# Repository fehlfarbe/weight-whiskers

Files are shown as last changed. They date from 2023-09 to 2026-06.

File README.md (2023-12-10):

# weight-whiskers

PCB top

This is an ESP32 S2 based smart scale that tracks my cat's weight and sends data via MQTT to my smart home. I did the project to automatically track my sick cat's weight when he visits his toilet. Unfortunately he died in August 2023. So this is dedicated to you, my beloved Schneeball 🖤🌈

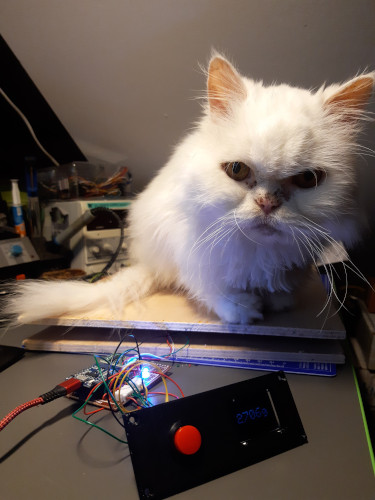
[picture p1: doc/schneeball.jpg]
Schneeball

Schneeball testing the scale

# Hardware

I made a prototype on a solder board with an ESP32 S2 breakout board. I like the WEMOS S2 mini which is very small. You might have to change some pins. Or just use the gerber files and make the PCB. You can find the KiCAD project and gerber files at [hardware](hardware/).

You can connect all load cells that are compatible with the HX711 IC. I'm using [four cells that can measure up to 50Kg](https://de.aliexpress.com/item/1005004867068245.html) because it's easier to keep a big cat toilet balanced.

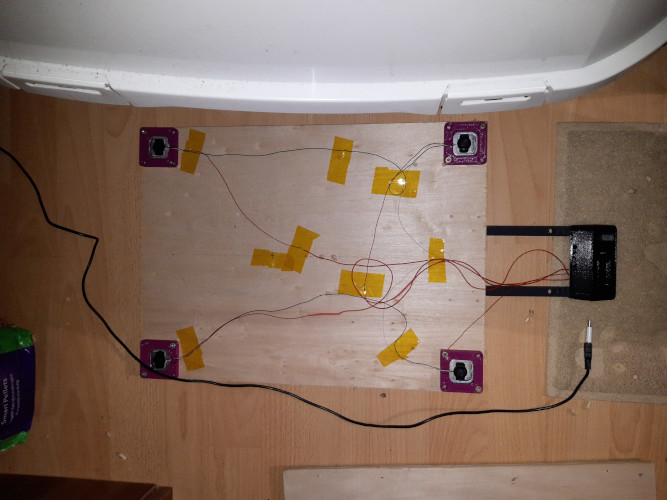
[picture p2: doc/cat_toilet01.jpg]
sensors
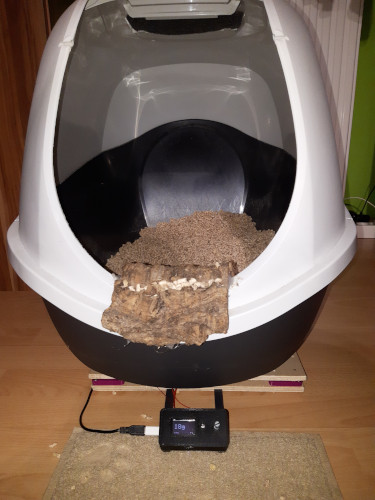
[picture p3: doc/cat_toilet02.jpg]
cat toilet with display
 

## Schematic

schematic
[PDF](doc/pcb_schematic.pdf)

## 2D plot

#### Front

**Important:** Check the VCC and GND position of the display! Some displays have GND on the first pin and VCC on the second like in the rendered image. You need a display with `VCC  | GND | SCL | SDA` pinout as you can see in the 2D front plot.

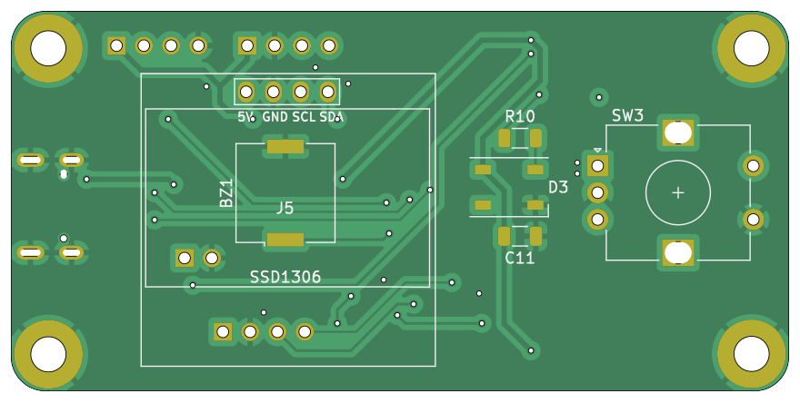
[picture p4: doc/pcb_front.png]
PCB render front PCB front


#### Back
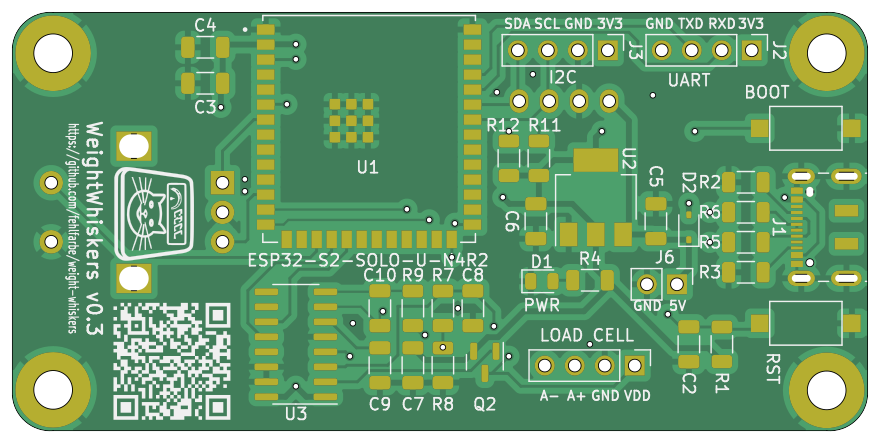
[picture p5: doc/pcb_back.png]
PCB render back PCB back


## 3D rendering

#### Front
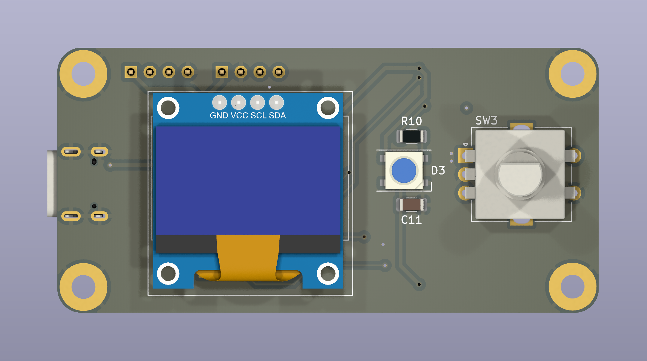
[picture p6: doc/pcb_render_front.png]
PCB render front


#### Back

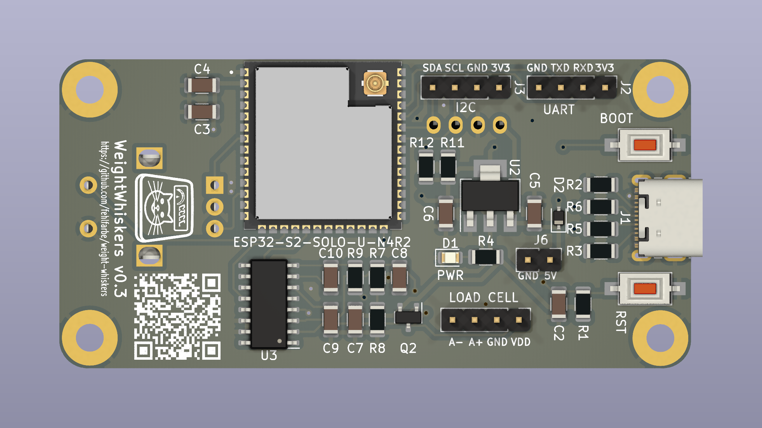
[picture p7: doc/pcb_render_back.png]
PCB render back


## Images
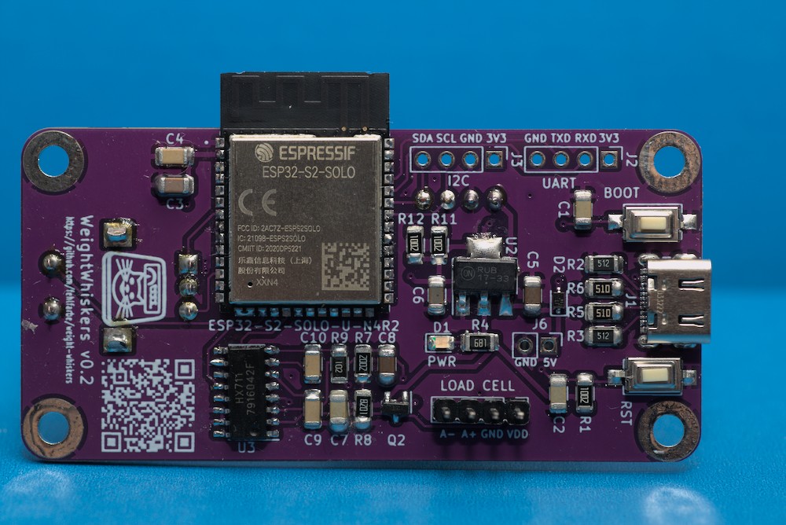
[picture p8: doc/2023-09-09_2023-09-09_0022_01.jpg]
PCB front

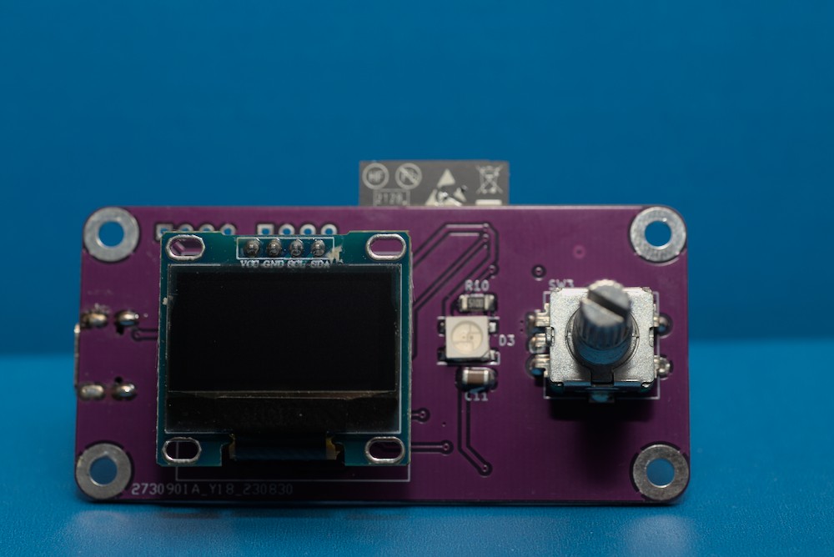
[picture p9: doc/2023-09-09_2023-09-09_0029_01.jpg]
PCB back


# Software

## Installation

Just install [PlatformIO](https://platformio.org/), clone the project, connect the device and run:
`pio run -t upload -e esp32s` to upload the sketch and `pio run -t uploadfs -e esp32s2` to upload the filesystem that contains the config file and web interface. Use the environment `-e esp32s2_ota` if you want to update the device via WiFi.
WARNING: When you update the filesystem you will overwrite the config file and measurements. So please backup it first!

# Usage

On first start the weight-whiskers scale will create an access point that has a config page at <http://192.168.4.1> where you can connect to your local WiFi. If the connection was successful you can find the actual web interface at <http://weight-whiskers.local> in your local network or check your internet router page to get the local IP address.

With a long press on the encoder you can calibrate the load cells with a known weight. The default weight is 500g but you can change it by rotating the encoder (or set it up on the web interface). Just follow the instructions on the display. To tare the scale just short press (<1s) the encoder button.

You can configure the `scale minimum weight` on the web interface. If the cat enters the scale, the LED lights up yellow and the scale measures the weight (with standard deviation) and duration until the cat left the scale. Afterwards the LED lights up green and the result will be stored in the CSV file and sent via MQTT message. If you connected the buzzer, a fancy sound will be played :D

## Web interface

On the web interface you can show, delete and down- and upload the data. The measurements are stored in a CSV file on the device. You can download it and open it in a text editor or import it with a spreadsheet editor. You can also edit the config and show the scale's live data.

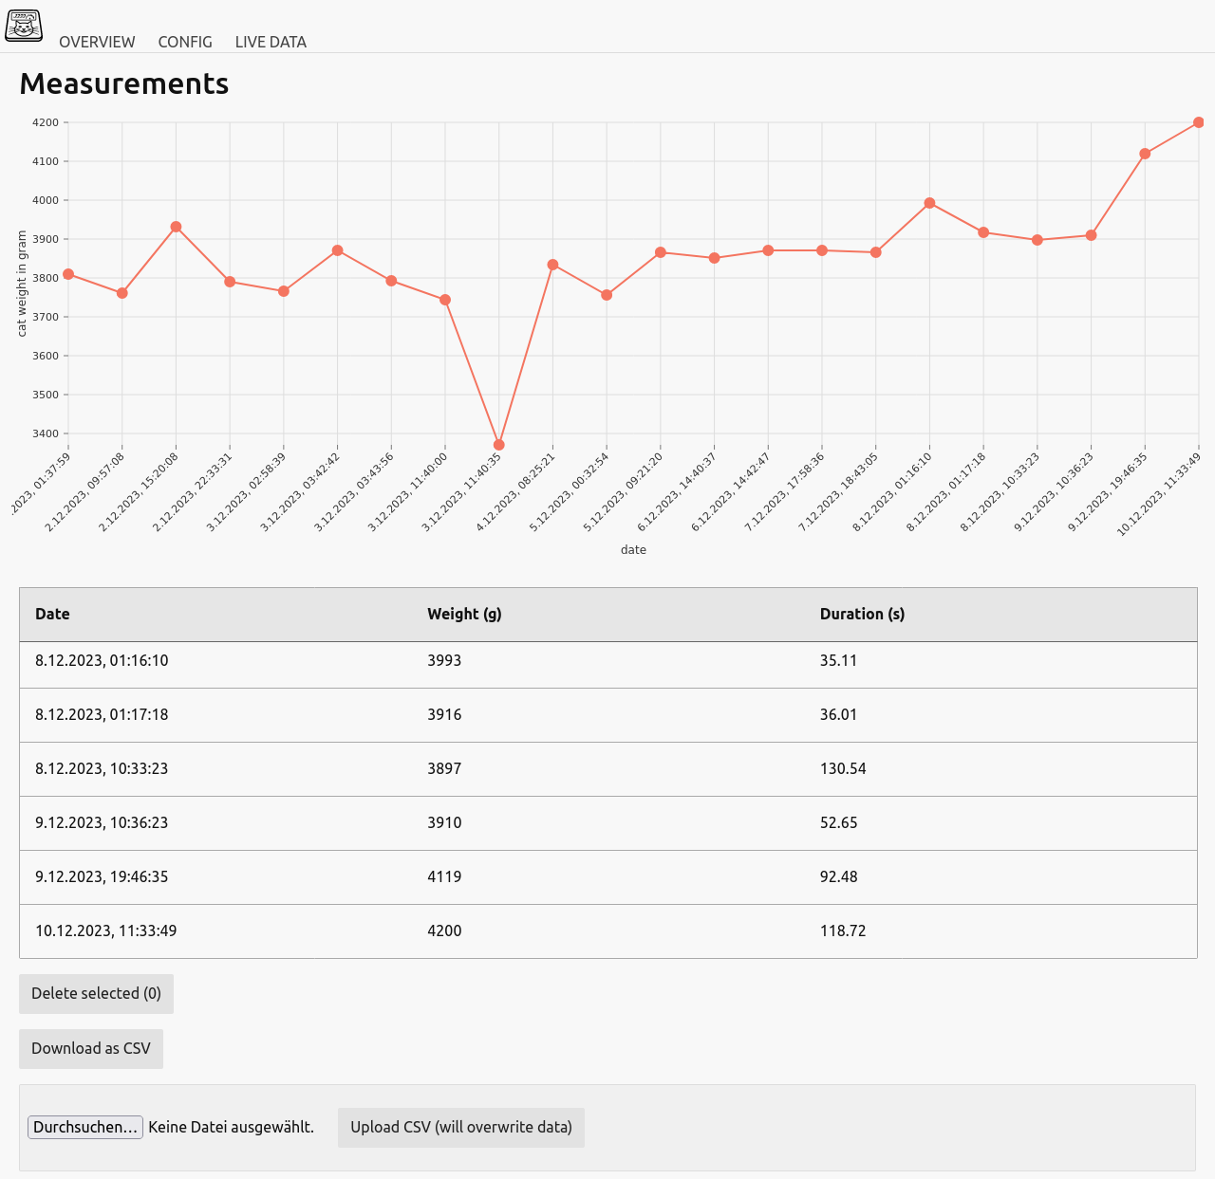
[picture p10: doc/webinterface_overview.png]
Web interface web interface
 
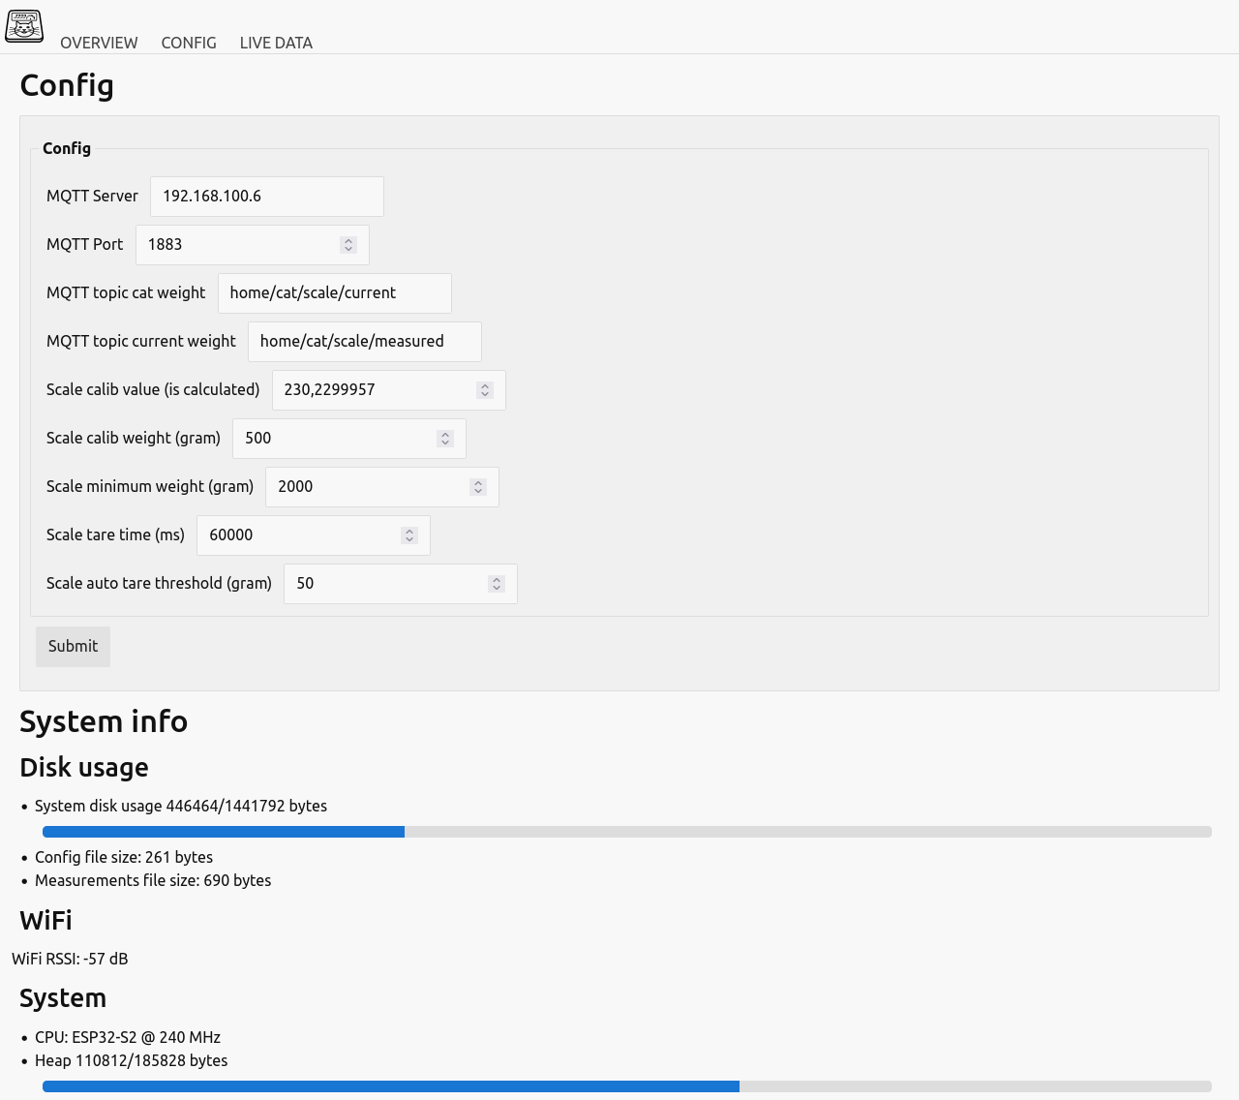
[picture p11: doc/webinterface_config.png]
Web interface web interface
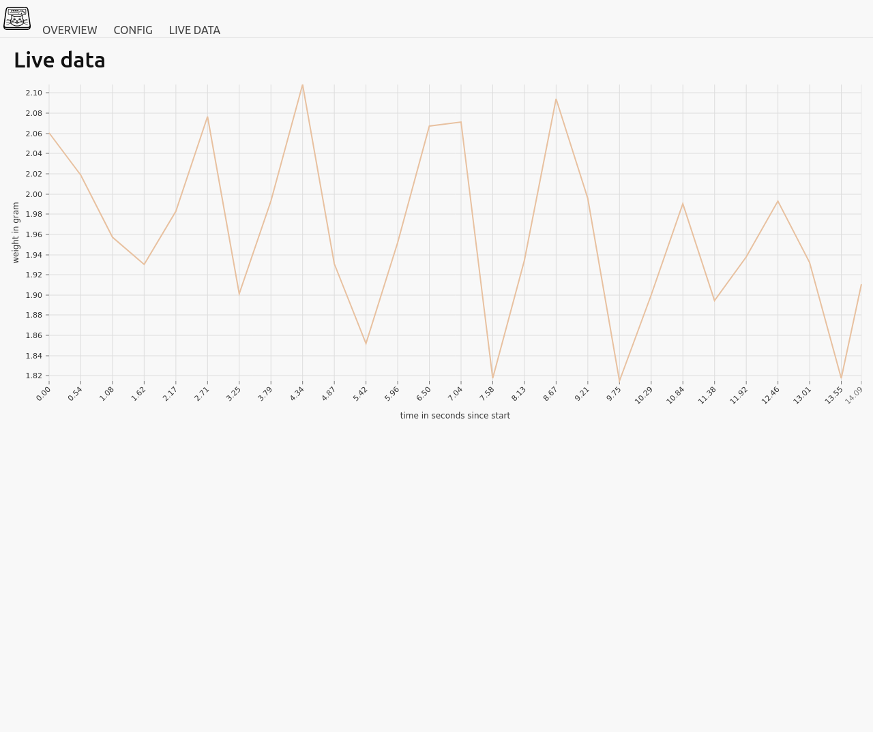
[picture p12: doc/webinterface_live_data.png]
Web interface web interface


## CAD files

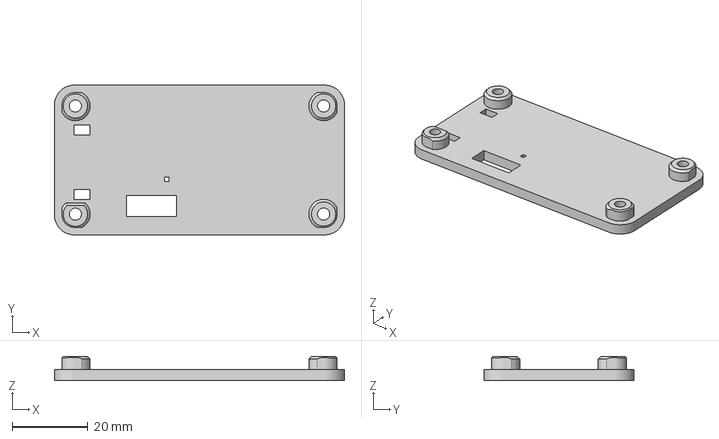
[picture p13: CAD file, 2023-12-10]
hardware/housing/weight-whiskers-back.3mf
76.5 x 39.5 x 6.42 mm

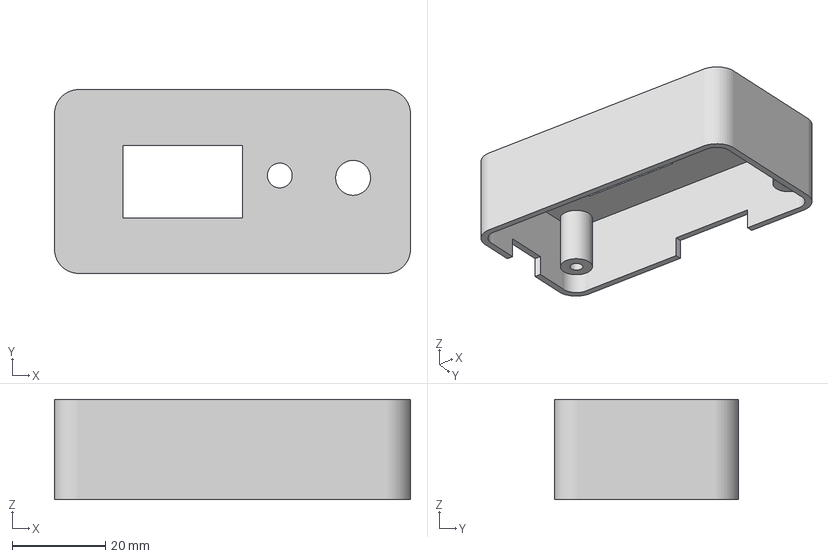
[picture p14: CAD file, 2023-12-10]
hardware/housing/weight-whiskers-housing.3mf
76.5 x 39.5 x 21.5 mm

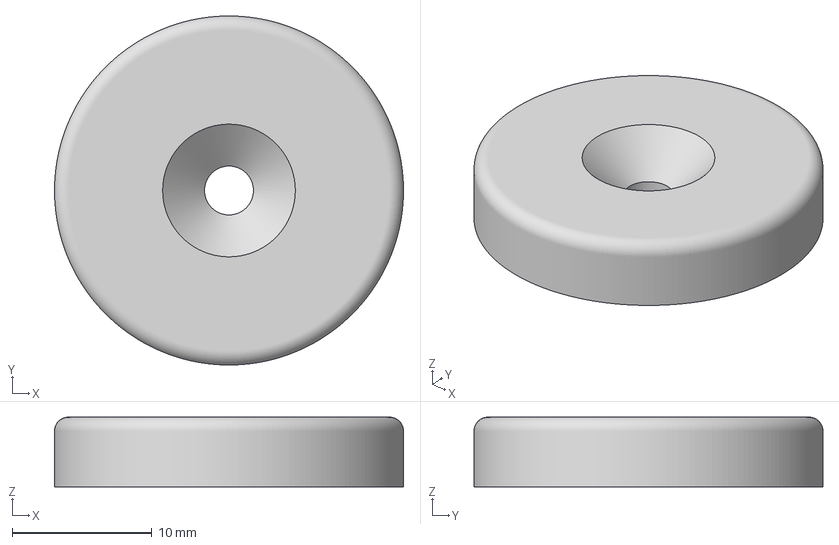
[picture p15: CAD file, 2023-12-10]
hardware/housing/weight-whiskers-foot.3mf
25.0 x 25.0 x 5.00 mm

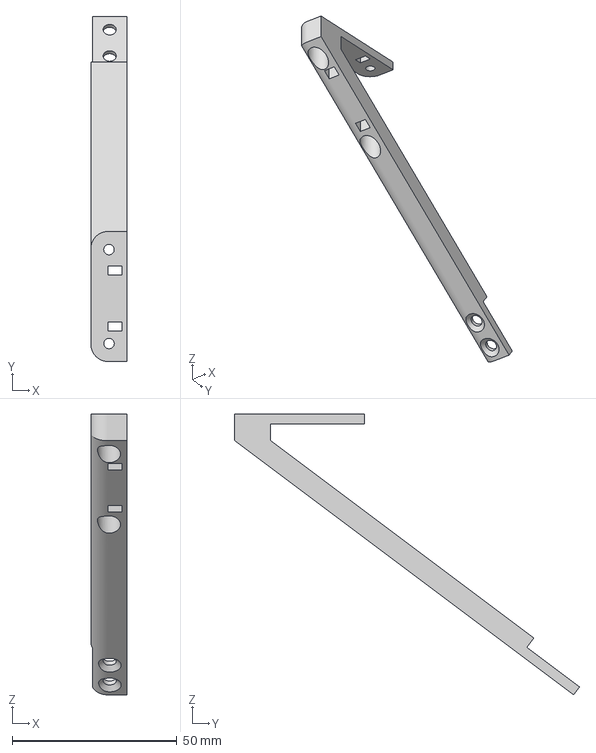
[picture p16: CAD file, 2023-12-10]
hardware/housing/weight-whiskers-stand.3mf
11.0 x 104.8 x 85.2 mm

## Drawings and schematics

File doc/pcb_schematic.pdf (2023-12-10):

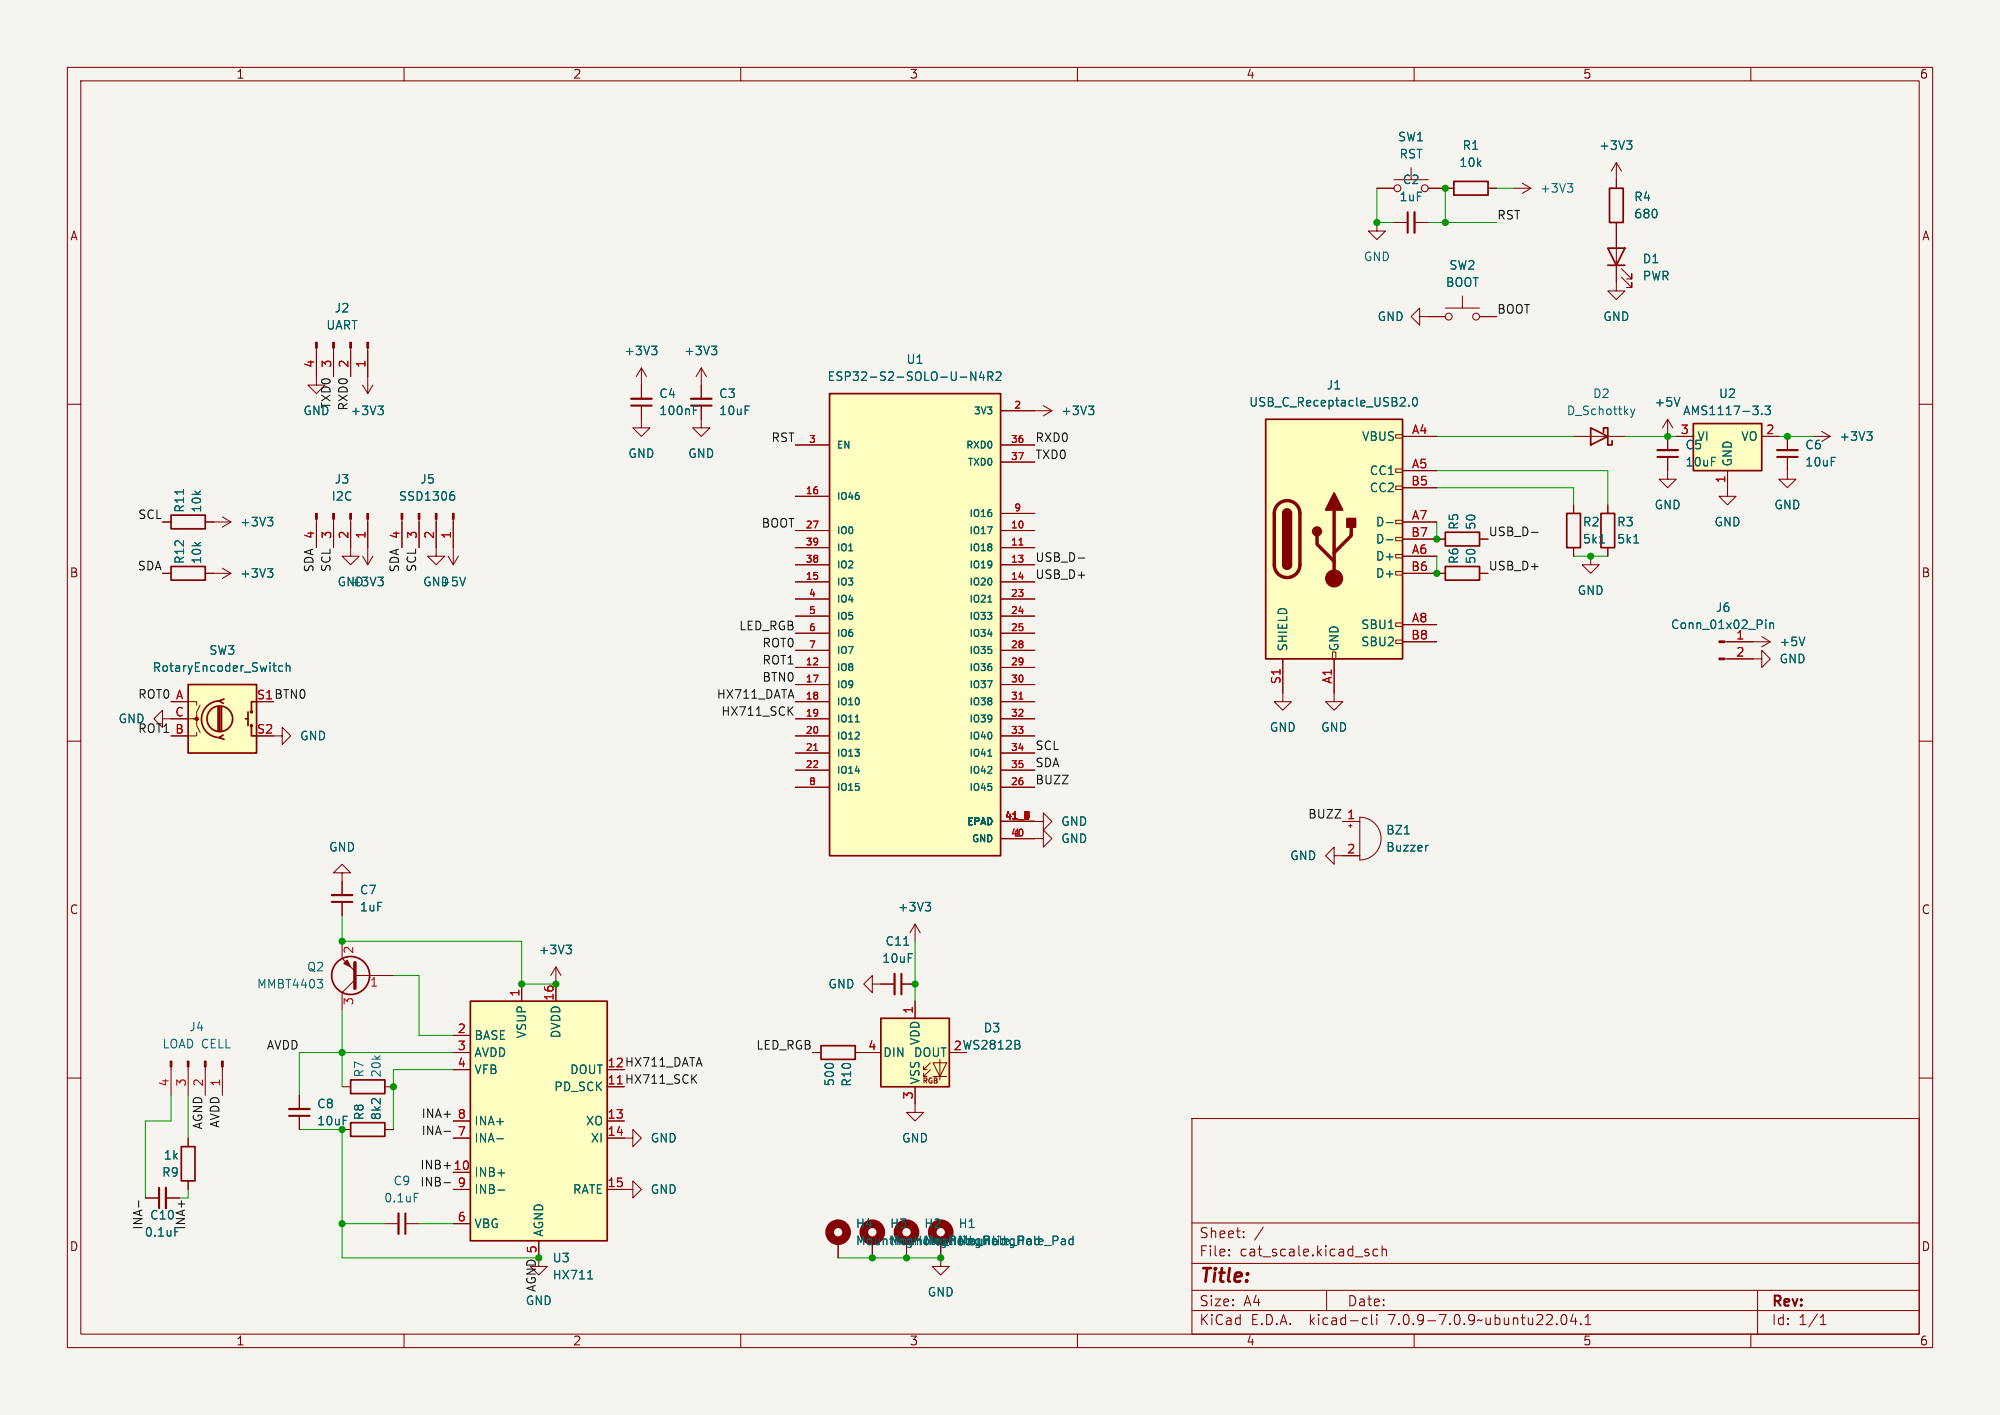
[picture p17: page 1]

Id: 1/1 Title: File: cat_scale.kicad_sch Sheet: /

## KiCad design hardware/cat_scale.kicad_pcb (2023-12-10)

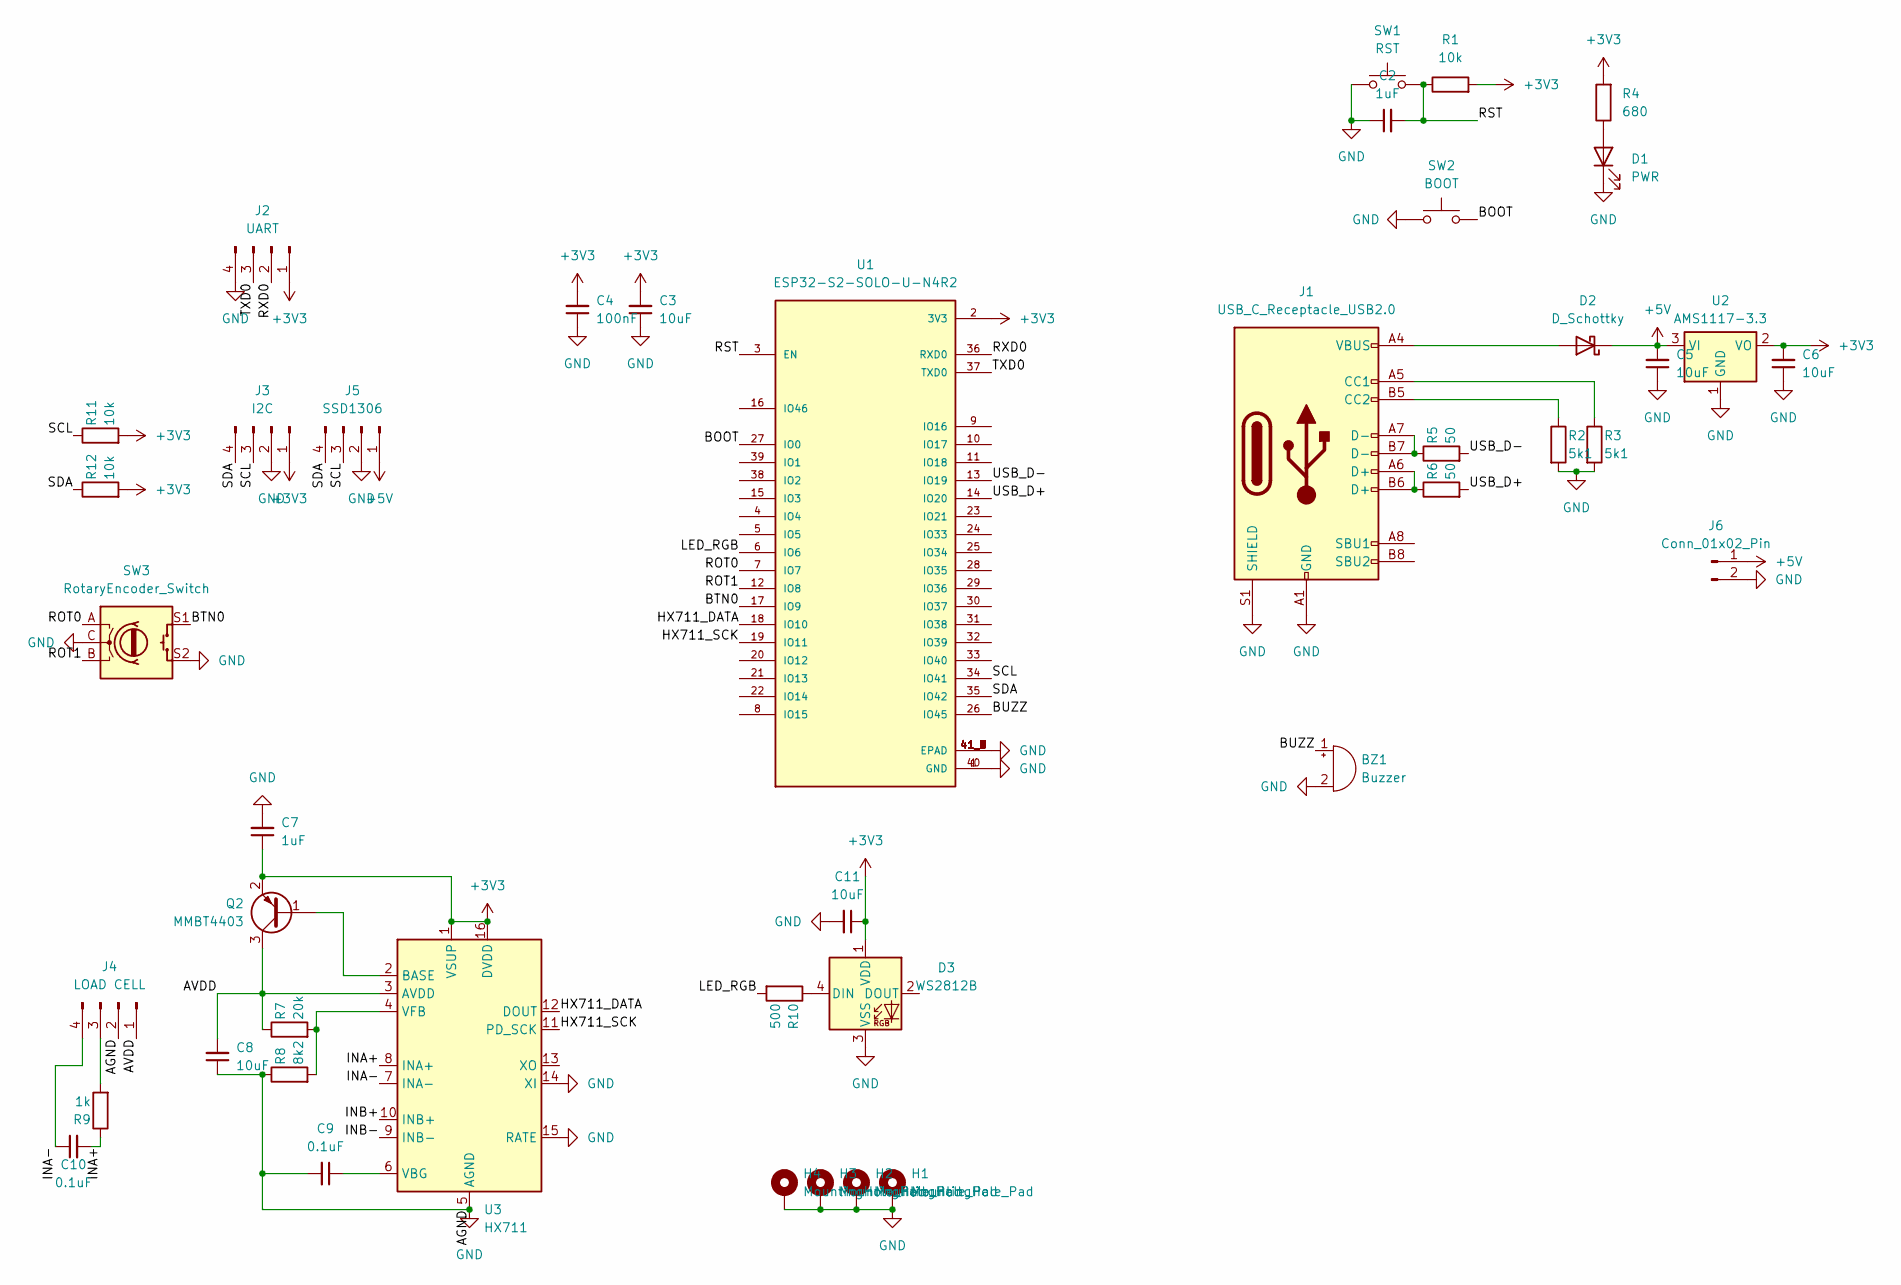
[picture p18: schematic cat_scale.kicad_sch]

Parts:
BZ1: Buzzer; Buzzer_Murata_PKMCS0909E
C2, C7: 1uF; C_1206_3216Metric
C3, C5, C6, C8, C11: 10uF; C_1206_3216Metric
C4: 100nF; C_1206_3216Metric
C9, C10: 0.1uF; C_1206_3216Metric
D1: PWR; LED_0805_2012Metric
D2: D_Schottky; D_SOD-323
D3: WS2812B; LED_WS2812B_PLCC4_5.0x5.0mm_P3.2mm
H1, H2, H3, H4: MountingHole_Pad; MountingHole_3.2mm_M3_Pad
J1: USB_C_Receptacle_USB2.0; USB_C_Receptacle_JAE_DX07S016JA1R1500
J2: UART; PinHeader_1x04_P2.54mm_Vertical
J3: I2C; PinHeader_1x04_P2.54mm_Vertical
J4: LOAD CELL; PinHeader_1x04_P2.54mm_Vertical
J5: SSD1306; 128x64OLED
J6: Conn_01x02_Pin; PinHeader_1x02_P2.54mm_Vertical
Q2: MMBT4403; SOT-23
R1, R11, R12: 10k; R_1206_3216Metric
R2, R3: 5k1; R_1206_3216Metric
R4: 680; R_1206_3216Metric
R5, R6: 50; R_1206_3216Metric
R7: 20k; R_1206_3216Metric
R8: 8k2; R_1206_3216Metric
R9: 1k; R_1206_3216Metric
R10: 500; R_1206_3216Metric
SW1: RST; SW_SPST_CK_RS282G05A3
SW2: BOOT; SW_SPST_CK_RS282G05A3
SW3: RotaryEncoder_Switch; RotaryEncoder_Alps_EC12E-Switch_Vertical_H20mm
U1: ESP32-S2-SOLO-U-N4R2; XCVR_ESP32-S2-SOLO-U-N4R2; PARTREV 1.4
U2: AMS1117-3.3; SOT-223-3_TabPin2
U3: HX711; SOP-16_3.9x9.9mm_P1.27mm

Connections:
+3V3: C3.2, C4.2, C6.2, C7.1, C11.1, D3.1 (VDD), J2.1, J3.1, Q2.2 (E), R1.2, R4.2, R11.2, R12.2, U1.2 (3V3), U2.2 (VO), U3.1 (VSUP), U3.16 (DVDD)
+5V: C5.2, D2.1 (K), J5.1, J6.1, U2.3 (VI)
/AVDD: C8.2, J4.1, Q2.3 (C), R7.1, U3.3 (AVDD)
/BOOT: SW2.2, U1.27 (IO0)
/BTN0: SW3.S1, U1.17 (IO9)
/BUZZ: BZ1.1 (-), U1.26 (IO45)
/HX711_DATA: U1.18 (IO10), U3.12 (DOUT)
/HX711_SCK: U1.19 (IO11), U3.11 (PD_SCK)
/INA+: C10.2, R9.1, U3.8 (INA+)
/INA-: C10.1, J4.4, U3.7 (INA-)
/INB+: U3.10 (INB+)
/INB-: U3.9 (INB-)
/LED_RGB: R10.2, U1.6 (IO6)
/ROT0: SW3.A, U1.7 (IO7)
/ROT1: SW3.B, U1.12 (IO8)
/RST: C2.2, R1.1, SW1.2, U1.3 (EN)
/RXD0: J2.2, U1.36 (RXD0)
/SCL: J3.3, J5.3, R11.1, U1.34 (IO41)
/SDA: J3.4, J5.4, R12.1, U1.35 (IO42)
/TXD0: J2.3, U1.37 (TXD0)
/USB_D+: R6.2, U1.14 (IO20)
/USB_D-: R5.2, U1.13 (IO19)
GND: BZ1.2 (+), C2.1, C3.1, C4.1, C5.1, C6.1, C7.2, C8.1, C9.2, C11.2, D1.1 (K), D3.3 (VSS), H1.1, H2.1, H3.1, H4.1, J1.A1 (GND), J1.A12 (GND), J1.B1 (GND), J1.B12 (GND), J1.S1 (SHIELD), J2.4, J3.2, J4.2, J5.2, J6.2, R2.2, R3.2, R8.1, SW1.1, SW2.1, SW3.C, SW3.S2, U1.1 (GND), U1.40 (GND), U1.41_1 (EPAD), U1.41_2 (EPAD), U1.41_3 (EPAD), U1.41_4 (EPAD), U1.41_5 (EPAD), U1.41_6 (EPAD), U1.41_7 (EPAD), U1.41_8 (EPAD), U1.41_9 (EPAD), U2.1 (GND), U3.5 (AGND), U3.14 (XI), U3.15 (RATE)
unnamed: D1.2 (A), R4.1
unnamed: D2.2 (A), J1.A4 (VBUS), J1.A9 (VBUS), J1.B4 (VBUS), J1.B9 (VBUS)
unnamed: D3.4 (DIN), R10.1
unnamed: J1.A5 (CC1), R3.1
unnamed: J1.B5 (CC2), R2.1
unnamed: J1.A6 (D+), J1.B6 (D+), R6.1
unnamed: J1.A7 (D-), J1.B7 (D-), R5.1
unnamed: J4.3, R9.2
unnamed: Q2.1 (B), U3.2 (BASE)
unnamed: C9.1, U3.6 (VBG)
unnamed: R7.2, R8.2, U3.4 (VFB)

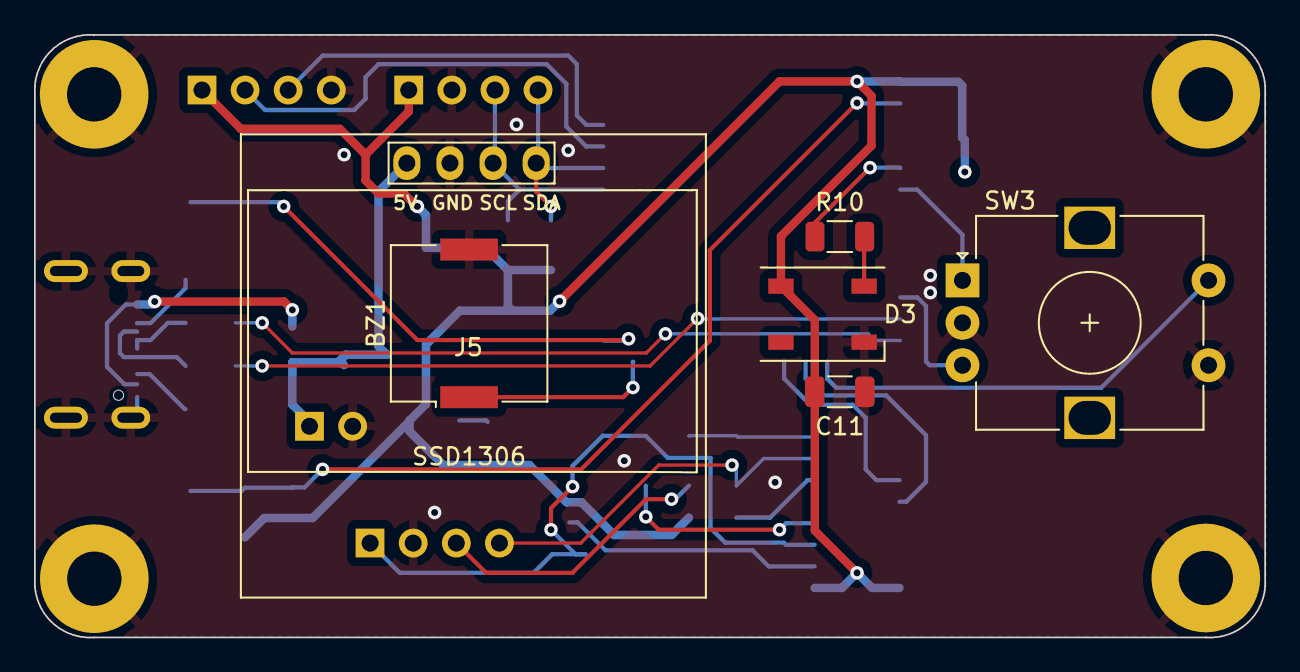
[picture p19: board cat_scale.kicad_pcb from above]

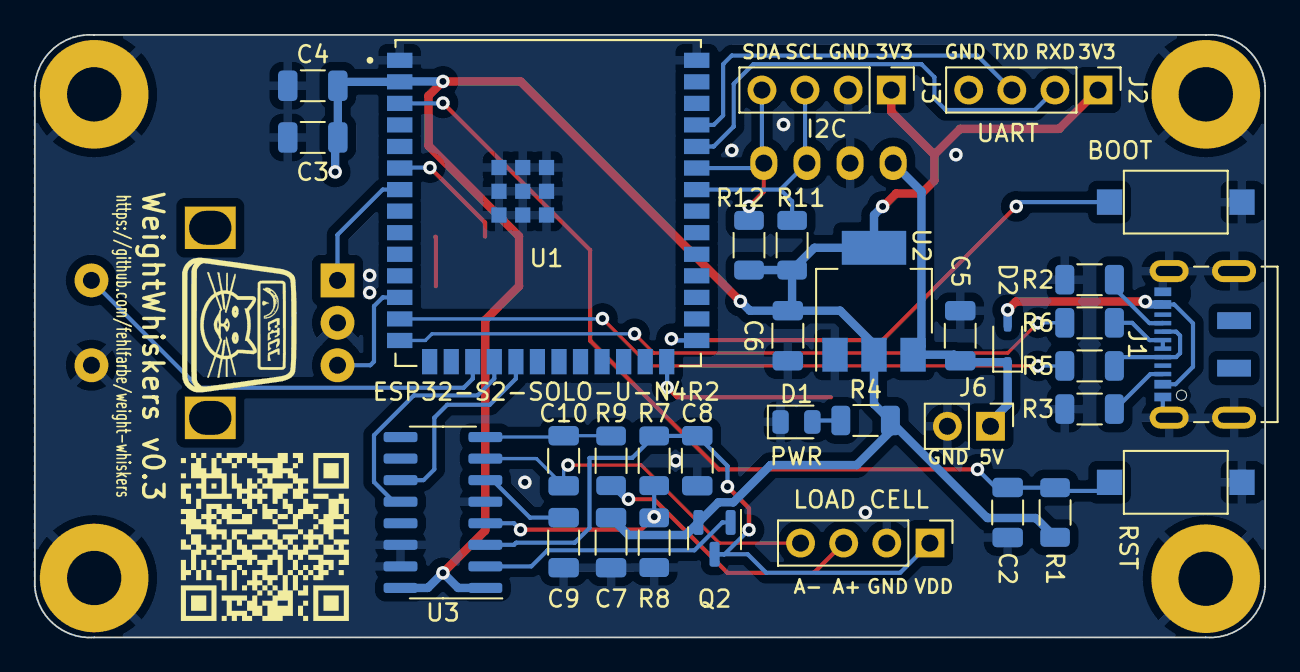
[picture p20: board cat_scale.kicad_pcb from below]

Board: 2 copper layers, 72.5 x 35.5 mm, 43 parts (33 on the bottom side), 32 nets.

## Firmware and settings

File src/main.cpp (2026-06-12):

#include <Arduino.h>
#include <Wire.h>
#include <HX711.h>
#include <LittleFS.h>
#include <Bounce2.h>
#include <AiEsp32RotaryEncoder.h>
#include <WiFi.h>
#include <DNSServer.h>
#include <WebServer.h>
#include <ESPAsyncWebServer.h>
#include <ESPAsyncWiFiManager.h>
#include <ESPmDNS.h>
#include <PubSubClient.h>
#include <FastLED.h>
#include <Filters.h>
#include <ArduinoOTA.h>
#include <AsyncJson.h>
#include <ArduinoJson.h>
#include <melody_player.h>
#include <melody_factory.h>
#include "Display.h"

// Debug
#define SAVE_RAW_VAL 0
// Button
#define ENCODER_BTN 9
#define ENCODER_A 7
#define ENCODER_B 8
// LED
#define LED_EXTRA 6
#define LED_NUM 1
// HX711 circuit wiring
#define LOADCELL_DOUT_PIN 10
#define LOADCELL_SCK_PIN 11
// Display
#define SDA 42
#define SCL 41
// #define SDA 34
// #define SCL 33
#define SSD1306_NO_SPLASH
// Buzzer
#define BUZZER 45
// constants
#define SCALE_DELAY_MS 100
#define SCALE_WS_DELAY_MS 500
#define BUFSIZE 55
#define JSON_BUFFER 2048

#define TAG "WeightWhiskers"

using namespace weightwhiskers;

// display
Display display(&Wire);

// buttons
AiEsp32RotaryEncoder encoder(ENCODER_B, ENCODER_A, ENCODER_BTN, -1, 4, true);

// LED
CRGBArray<LED_NUM> leds;

// buzzer
MelodyPlayer buzzer(BUZZER, 0, LOW);

// scale
HX711 scale;
long scaleLastTimestamp = 0;
long scaleLastWSTimestamp = 0;
long scaleLastTareThreshTimestamp = 0;
FilterOnePole weightLowPass = FilterOnePole(LOWPASS, 0.5, 0);
// DEBUG
time_t startTime = 0;

struct CatMeasurement {
    // UNIX timetamp in seconds
    time_t time = 0;
    // weight in gram
    uint16_t weight = 0.;
    // standard deviation
    float std = 0.;
    // duration in seconds
    float duration = 0.;
    // weight of poo/urine "dropping"
    uint16_t weightDropping = 0;
};
CatMeasurement lastMeasurement;

// fs::LittleFSFS fsWWW;
// fs::LittleFSFS fsConfig;
#define fsWWW LittleFS
#define fsConfig LittleFS
String measurementsFile = "/measurements.csv";
String configFile = "/config.json";

// Config
struct Config {
    // MQTT
    bool mqtt_enabled = false;
    String mqtt_server = "";
    int mqtt_port = 1883;
    String mqtt_user = "kitty";
    String mqtt_pass = "kitty";
    String mqtt_topic_cat_weight = "home/cat/scale/measured";
    String mqtt_topic_current_weight = "home/cat/scale/current";
    // scale
    float scale_calib_value = 1.f;
    int scale_calib_weight = 500; // gram
    int scale_weight_min = 2000; // gram
    // scale tare triggers
    int scale_tare_time = 60000; // millis
    int scale_tare_thresh = 50; // gram
    // presence detection
    float presence_time_min = 5.f;
    // weight deviation filter (0.0 = disabled, 0.2 = ±20%)
    float scale_weight_deviation_percent = 0.f;
};

Config config;

// Weight history for deviation filter (circular buffer for last 5 measurements)
#define WEIGHT_HISTORY_SIZE 5
uint16_t weightHistory[WEIGHT_HISTORY_SIZE] = {0};
int weightHistoryCount = 0; // how many valid measurements we have (0-5)
int weightHistoryIndex = 0; // current write position in circular buffer

// MQTT
TaskHandle_t pTaskMQTT;
QueueHandle_t qMQTT = xQueueCreate(5, sizeof(CatMeasurement));
SemaphoreHandle_t semMQTT;

// WiFi
WiFiClient espClient;
PubSubClient mqtt(espClient);
DNSServer dns;
AsyncWebServer server(80);
AsyncWiFiManager wifiManager(&server, &dns);
AsyncWebSocket ws("/ws");

// declarations
bool loadConfig();
bool saveConfig();
void printConfig();
void applyConfig();
void listDir(fs::FS& fs, const char* dirname, uint8_t levels);
void setupScale();
void tare(int count);
void calibrate(long weight);
void apCallback(AsyncWiFiManager* mgr);
void WiFiEvent(WiFiEvent_t event);
void handleConfig(AsyncWebServerRequest* request);
void handleConfigUpdate(
    AsyncWebServerRequest* request, uint8_t* data, size_t len, size_t index, size_t total);
void handeMeasurementsUpload(AsyncWebServerRequest* request, String filename, size_t index,
    uint8_t* data, size_t len, bool final);
void handleMeasurements(AsyncWebServerRequest* request);
void handleSystem(AsyncWebServerRequest* request);
void onEvent(AsyncWebSocket* server, AsyncWebSocketClient* client, AwsEventType type, void* arg,
    uint8_t* data, size_t len);
void setupMQTT();
void sendMQTTCatWeights(const CatMeasurement& measurement);
void createMeasurementsFile();
void initWeightHistory();
void addToWeightHistory(uint16_t weight);
float calculateAverageWeight();
bool isMeasurementValid(uint16_t weight, float deviationPercent);
bool writeMeasurement(CatMeasurement& m);
void playToneStart();
void playToneSuccess();
void taskMQTT(void* parameter);

void IRAM_ATTR readEncoderISR() { encoder.readEncoder_ISR(); }

void setup()
{
    esp_log_level_set(TAG, ESP_LOG_VERBOSE);

    // Serial
    Serial.begin(115200);
    Serial.setDebugOutput(true);
    ESP_LOGI(TAG, "Weight whiskers");

    // setup pins
    pinMode(BUZZER, OUTPUT);
    digitalWrite(BUZZER, LOW);

    // setup encoder
    encoder.begin();
    encoder.setup(readEncoderISR);
    encoder.disableAcceleration();

    // display
    Wire.begin(SDA, SCL);
    display.begin();
    display.drawBootScreen();

    // LED
    FastLED.addLeds<NEOPIXEL, LED_EXTRA>(leds, LED_NUM);
    FastLED.setBrightness(50);
    leds[0] = CRGB::Yellow;
    FastLED.show();

    // start sound
    playToneStart();

    // config filesystem and config
    if (!fsConfig.begin(true, "/littlefs", 10, "spiffs")) {
        ESP_LOGE(TAG, "An Error has occurred while mounting config");
        display.drawError("FS Error");
        while (true) {
            leds[0] = CRGB::Red;
            FastLED.show();
            delay(500);
            leds[0] = CRGB::Black;
            FastLED.show();
            delay(500);
        }
    }

    // load config or create config file with default values if not existing
    listDir(fsConfig, "/", 4);
    if (!loadConfig()) {
        ESP_LOGI(TAG, "Cannot load config, saving default config file");
        saveConfig();
    }
    printConfig();

    // create measurements file if not existing
    createMeasurementsFile();
    
    // initialize weight history from existing measurements
    initWeightHistory();

    listDir(fsConfig, "/", 4);

    // Setup WiFi
    ESP_LOGI(TAG, "WiFi autoconnect...");
    display.drawWiFi();
    WiFi.setAutoReconnect(true);
    WiFi.onEvent(WiFiEvent);
    wifiManager.setAPCallback(apCallback);
    if (!wifiManager.autoConnect("weight-whiskers")) {
        Serial.println("failed to connect, we should reset as see if it connects");
    }

    // setup mDNS
    MDNS.begin("weight-whiskers");
    ESP_LOGI(TAG, "Visit the config site at http://weight-whiskers.local");

    // Set up required URL handlers on the web server.
    // static files, cached for 1 month
    // if (!fsWWW.begin(true, "/www", 10, "www")) {
    //     Serial.println("An Error has occurred while mounting www");
    //     display.drawError("FS Error");
    //     while (true) {
    //         leds[0] = CRGB::Yellow;
    //         FastLED.show();
    //         delay(500);
    //         leds[0] = CRGB::Black;
    //         FastLED.show();
    //         delay(500);
    //     }
    // }
    listDir(fsWWW, "/", 4);
    server.serveStatic("/", fsWWW, "/www/")
        .setDefaultFile("index.html")
        .setCacheControl("max-age=2678400");
    server.serveStatic("/config", fsWWW, "/www/index.html")
        .setDefaultFile("index.html")
        .setCacheControl("max-age=2678400");
    server.serveStatic("/live", fsWWW, "/www/index.html")
        .setDefaultFile("index.html")
        .setCacheControl("max-age=2678400");
    server.on("/api/config", HTTP_POST, handleConfig, nullptr, handleConfigUpdate);
    server.on("/api/measurements", HTTP_POST, handleMeasurements, handeMeasurementsUpload);
    server.on("/api/raw", HTTP_GET, [](AsyncWebServerRequest* request) {
        request->send(fsConfig, "/rawvalues.csv", "text/csv");
    });
    server.on("/api/system", HTTP_GET, handleSystem);
    server.on("/api/reboot", HTTP_GET, [](AsyncWebServerRequest* request) { ESP.restart(); });
    // attach AsyncWebSocket
    ws.onEvent(onEvent);
    server.addHandler(&ws);
    server.begin();

    // setup time
    display.drawText("NTP...");
    configTime(0, 0, "pool.ntp.org");
    time(&startTime);

    // setup MQTT
    semMQTT = xSemaphoreCreateBinary();
    xSemaphoreGive(semMQTT);
    setupMQTT();
    xTaskCreate(taskMQTT, "taskMQTT", getArduinoLoopTaskStackSize(), NULL, 1, &pTaskMQTT);

    // setup scale
    setupScale();

    // setup OTA
    ArduinoOTA.setHostname("weight-whiskers");
    ArduinoOTA.setPassword("weight-whiskers");

    ArduinoOTA.onStart([]() {
        ESP_LOGI(TAG, "Start");
        display.drawOTA(0);
    });
    ArduinoOTA.onEnd([]() {
        ESP_LOGI(TAG, "OTA Finished!");
        display.drawOTA(1.);
    });
    ArduinoOTA.onProgress([](unsigned int progress, unsigned int total) {
        float percentage = (1. / total) * progress;
        ESP_LOGI(TAG, "Update:%u%%\r", percentage * 100);
        display.drawOTA(percentage);
    });
    ArduinoOTA.onError([](ota_error_t error) {
        ESP_LOGE(TAG, "Error[%u]: ", error);
        display.drawOTA(0);
        if (error == OTA_AUTH_ERROR)
            ESP_LOGE(TAG, "Auth Failed");
        else if (error == OTA_BEGIN_ERROR)
            ESP_LOGE(TAG, "Begin Failed");
        else if (error == OTA_CONNECT_ERROR)
            ESP_LOGE(TAG, "Connect Failed");
        else if (error == OTA_RECEIVE_ERROR)
            ESP_LOGE(TAG, "Receive Failed");
        else if (error == OTA_END_ERROR)
            ESP_LOGE(TAG, "End Failed");
    });
    ArduinoOTA.begin();

    // success!
    leds[0] = CRGB::Green;
    FastLED.show();
    ESP_LOGI(TAG, "Setup finished!");
}

void loop()
{
    // clear ws clients
    ws.cleanupClients();

    // over the air update
    ArduinoOTA.handle();

    // button handling
    if (encoder.isEncoderButtonClicked()) {
        tare(10);
    } else {
        auto beforeDown = millis();
        while (encoder.isEncoderButtonDown()) {
            auto now = millis();
            if ((now - beforeDown) > 1000) {
                calibrate(config.scale_calib_weight);
            }
        }
    }

    // measure weight
    auto current = millis();
    if (scale.wait_ready_timeout(1000)) {
        auto weight = scale.get_units(2);
        auto raw = scale.get_value();
        weightLowPass.input(weight);
        // weightLowPass.print();
        ESP_LOGV(TAG, "Current measurement=%fg raw=%f lowPass=%f Y=%f up since=%d\n", weight, raw,
            weightLowPass.output(), weightLowPass.Y, startTime);
        if (current - scaleLastWSTimestamp > SCALE_WS_DELAY_MS) {
            ws.printfAll("{\"timestamp\": %lu, \"weight\": %f, \"weight_unfiltered\": %f}", current,
                weightLowPass.output(), weight);
            scaleLastWSTimestamp = current;
        }
    } else {
        ESP_LOGE(TAG, "HX711 not found.");
        return;
    }

    if (current - scaleLastTimestamp > SCALE_DELAY_MS) {
        if (weightLowPass.output() > config.scale_weight_min) {
// debug: write values to file
#ifdef SAVE_RAW_VAL
            File rawValues = fsConfig.open("/rawvalues.csv", FILE_WRITE);
            rawValues.println("time,raw,mean,std");
#endif
            // cat sits on the throne
            leds[0] = CRGB::Yellow;
            FastLED.show();
            // prepare duration and temp value
            auto presenceStart = current;
            long duration = 0;
            float bestWeightStd = infinityf();
            float bestWeight = 0;
            // prepare filter
            auto statistics = RunningStatistics();
            statistics.setWindowSecs(config.presence_time_min);
            statistics.setInitialValue(weightLowPass.output());
            // run measurement
            while (weightLowPass.output() > config.scale_weight_min) {
                auto value = scale.get_units(2);
                duration = (millis() - presenceStart) / 1000.;
                weightLowPass.input(value);
                statistics.input(value);
#ifdef SAVE_RAW_VAL
                rawValues.printf("%lu,%.2f,%.2f,%.2f\n", millis() - presenceStart, value,
                    statistics.mean(), statistics.sigma());
#endif
                display.drawWeightScreen(weightLowPass.output(), lastMeasurement.weight, (100./config.presence_time_min)*duration);
                // use value with lowes std dev when minimum presence time is reached
                if (duration > config.presence_time_min && statistics.sigma() < bestWeightStd) {
                    bestWeightStd = statistics.sigma();
                    bestWeight = statistics.mean();
                }
                delay(10);
            }
#ifdef SAVE_RAW_VAL
            rawValues.close();
#endif
            // cat left the throne, save measurement if minimum presence time was reached
            if (duration > config.presence_time_min) {
                ESP_LOGI(TAG, "Got new meowsurement!");
                // show success
                leds[0] = CRGB::Green;
                FastLED.show();
                display.drawWeightScreen(bestWeight, lastMeasurement.weight);
                playToneSuccess();
                // wait for settlement to measure droppings and write measurement
                delay(5000);
                CatMeasurement measurement;
                time(&measurement.time); // Get current timestamp
                measurement.weight = bestWeight;
                measurement.std = bestWeightStd;
                measurement.duration = duration;
                measurement.weightDropping = max(0, (int)scale.get_units(10));
                // write data to file
                writeMeasurement(measurement);
                // send data to MQTT
                if (config.mqtt_enabled) {
                    ESP_LOGI(TAG, "MQTT enabled, sending message to queue");
                    xQueueSend(qMQTT, &lastMeasurement, 0);
                } else {
                    ESP_LOGI(TAG, "MQTT not enabled");
                }
                // save last measurement
                lastMeasurement = measurement;
            }
            delay(1000);
            tare(10);
        }

        // write weight to display
        display.drawWeightScreen(weightLowPass.output(), lastMeasurement.weight);

        // tare if necessary
        if (abs(weightLowPass.output()) < config.scale_tare_thresh) {
            scaleLastTareThreshTimestamp = 0;
        } else {
            if (!scaleLastTareThreshTimestamp || current < scaleLastTareThreshTimestamp) {
                scaleLastTareThreshTimestamp = current;
            } else if (current - scaleLastTareThreshTimestamp > config.scale_tare_time) {
                tare(10);
            }
        }
    }

    // reset LED
    leds[0] = CRGB::Black;
    FastLED.show();
}

void setupScale()
{
    display.drawText("Setup scale");
    scale.begin(LOADCELL_DOUT_PIN, LOADCELL_SCK_PIN);
    scale.set_scale(config.scale_calib_value); // set calibrated scale value from config
    tare(10);
}

void tare(int count = 10)
{
    display.drawTare();
    scale.tare(count);
}

void calibrate(long weight)
{
    ESP_LOGI(TAG, "Calibrate...");

    // setup scale
    scale.set_scale();
    scale.tare();

    // place weight
    display.drawCalib(weight);
    Serial.printf("Place %ld and press\n", weight);
    // wait for button release
    while (encoder.isEncoderButtonDown()) {
        delay(10);
    }
    // wait for button press
    encoder.reset();
    long difference = 0;
    while (!encoder.isEncoderButtonDown()) {
        difference = encoder.readEncoder();
        Serial.printf("Difference %ld %d\n", difference, encoder.encoderChanged());
        display.drawCalib(weight + difference);
        Serial.printf("Place %ld and press\n", weight + difference);
    }
    Serial.println("clicked");
    encoder.reset();
    while (encoder.isEncoderButtonDown()) {
        delay(10);
    }
    weight += difference;

    // show state
    display.drawText("Calibrating...");

    // measure and calculate scale
    float value = scale.get_units(10) / weight;
    scale.set_scale(value);

    // write to file
    Serial.printf("Write scale %f to file\n", value);
    config.scale_calib_value = value;
    saveConfig();

    // show ok!
    display.drawText("Calibrated!");
    Serial.printf("Calibrated!\n");
    delay(1000);
}

void listDir(fs::FS& fs, const char* dirname, uint8_t levels)
{
    Serial.printf("Listing directory: %s\n", dirname);

    File root = fs.open(dirname, FILE_READ, false);
    if (!root) {
        Serial.println("Failed to open directory");
        return;
    }
    if (!root.isDirectory()) {
        Serial.println("Not a directory");
        return;
    }

    File file = root.openNextFile();
    while (file) {
        if (file.isDirectory()) {
            Serial.print("  DIR : ");
            Serial.println(file.name());
            if (levels) {
                listDir(
                    fs, (String(dirname) + String("/") + String(file.name())).c_str(), levels - 1);
            }
        } else {
            Serial.print("  FILE: ");
            Serial.print(file.name());
            Serial.print("  SIZE: ");
            Serial.println(file.size());
        }
        file = root.openNextFile();
    }
}

void apCallback(AsyncWiFiManager* mgr)
{
    Serial.println("Started AP");
    display.drawWiFiAPMode();
    leds[0] = CRGB::Blue;
    FastLED.show();
}

/**
 * @brief handles WiFi events and auto reconnects
 *
 */
void WiFiEvent(WiFiEvent_t event)
{
    switch (event) {
    case ARDUINO_EVENT_WIFI_AP_START:
        ESP_LOGI(TAG, "AP Started");
        leds[0] = CRGB::Blue;
        FastLED.show();
        break;
    case ARDUINO_EVENT_WIFI_AP_STACONNECTED:
        ESP_LOGI(TAG, "AP user connected");
        leds[0] = CRGB::Aqua;
        FastLED.show();
        break;
    case ARDUINO_EVENT_WIFI_AP_STOP:
        ESP_LOGI(TAG, "AP Stopped");
        break;
    case ARDUINO_EVENT_WIFI_STA_START:
        ESP_LOGI(TAG, "STA Started");
        break;
    case ARDUINO_EVENT_WIFI_STA_CONNECTED:
        ESP_LOGI(TAG, "STA Connected");
        break;
    case ARDUINO_EVENT_WIFI_STA_GOT_IP6:
        ESP_LOGI(TAG, "STA IPv6: ");
        // ESP_LOGI( TAG, "%s", WiFi.localIPv6().toString());
        break;
    case ARDUINO_EVENT_WIFI_STA_GOT_IP:
        // ESP_LOGI( TAG, "STA IPv4: ");
        ESP_LOGI(TAG, "%s", WiFi.localIP().toString().c_str());
        break;
    case ARDUINO_EVENT_WIFI_STA_DISCONNECTED:
    case ARDUINO_EVENT_WIFI_STA_LOST_IP:
        ESP_LOGI(TAG, "STA Disconnected -> reconnect");
        WiFi.reconnect();
        break;
    case ARDUINO_EVENT_WIFI_STA_STOP:
        ESP_LOGI(TAG, "STA Stopped");
        break;
    default:
        break;
    }
    ESP_LOGI(TAG, "WiFi mode %d", WiFi.getMode());
}

void handleConfig(AsyncWebServerRequest* request)
{
    // printConfig();
    ESP_LOGI(TAG, "serving config");
    request->send(fsConfig, configFile, "application/json");
}

void handleConfigUpdate(
    AsyncWebServerRequest* request, uint8_t* data, size_t len, size_t index, size_t total)
{
    ESP_LOGI(TAG, "Update config. Config size: %d/%d bytes", len, total);
    if (len == total) {
        DynamicJsonDocument doc(JSON_BUFFER);
        DeserializationError error = deserializeJson(doc, data);

        // Test if parsing succeeds.
        if (error) {
            ESP_LOGE(TAG, "deserializeJson() failed: %s", error.c_str());
            request->send(500, "text/html", error.c_str());
            return;
        }

        // open file
        File file = fsConfig.open(configFile, FILE_WRITE);

        // Serialize JSON to file
        if (serializeJson(doc, file) == 0) {
            ESP_LOGE(TAG, "Failed to write to file");
            request->send(500, "text/html", "Failed to write to file");
            return;
        }

        // Close the file
        file.close();

        // load config and apply new settings

        loadConfig();
        applyConfig();
    }
}

void handeMeasurementsUpload(AsyncWebServerRequest* request, String filename, size_t index,
    uint8_t* data, size_t len, bool final)
{
    ESP_LOGI(TAG, "Replace measurements file. CSV size: %d bytes\n", len);
    // open new file if index is zero, else append data
    File file = fsConfig.open(measurementsFile, index == 0 ? FILE_WRITE : FILE_APPEND);

    // write data
    file.write(data, len);

    // Close the file
    file.close();
}
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

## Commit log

2023-07-14 Added PCB layout
    [cat_scale.kicad_pcb, cat_scale.kicad_sch]
2023-08-02 Fixed PCB design
    [cat_scale.csv, cat_scale.kicad_pcb, cat_scale.kicad_sch]
2023-08-10 * Cleanup dependencies * Enabled ArduinoOTA * Added WebSocket sender for live data * Improved button handling for tare/calibration
2023-08-26 * Refactoring: moved display stuff to class * measurements contain duration instead of variance * added minimum presence time to config * added support for buzzer that plays a sound after cat finishe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
    [main.cpp]
2023-08-26 * PCB: Added buzzer
    [cat_scale.kicad_pcb, cat_scale.kicad_sch]
2023-09-15 * Added encoder support to change calibration weight * Added buzzer that plays a melody on start/measurement
    [main.cpp]
2023-09-15 Updated PCB and added images of the PCB to README
    [cat_scale.kicad_pcb]
2023-09-15 Added new arguments to encoder constructor
2023-12-05 Connect live measurements WebSocket to current host
2023-12-10 Updated PCB and README
    [cat_scale-B_Cu.gbr, cat_scale-B_Mask.gbr, cat_scale-B_Paste.gbr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]
2024-01-16 * Fixed bug in WiFi reconnect * Saving measurement with lowest std deviation * Plotting std deviation hose in web interface * Saving measurement with lowest std deviation
    [main.cpp]
2024-02-14 Added simple time filter for web interface Measurements page
2024-02-14 Additional time filter for web interface Measurements page
2024-02-14 Fixed negative / too big values for droppings in csv data
    [main.cpp]
2024-02-15 Fixed date format bug in filtering measurements
2024-10-10 * Updated ESPAsyncWebServer * added some debug output for WebSocket * added custom partitions.csv
    [partitions.csv]
2025-01-11 Added reboot API command
    [main.cpp]
2025-10-27 Fix crashes because off filled MQTT measurements buffer
    [main.cpp]
2026-06-12 added filter for unreasonable measurements
2026-06-12 Moved CSV download and upload to "config" section
    [cat_scale.kicad_sch]
